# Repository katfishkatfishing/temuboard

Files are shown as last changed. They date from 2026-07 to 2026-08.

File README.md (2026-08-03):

# temuboard



A compact 75% mechanical keyboard taken inspiration from the Keycool 84, that has a rotary encoder, and a small OLED display.

---

## Features

- **79 keys**
- **EC11 Rotary Encoder** - rotation bound to volume
- **128x64 I2C Display** - to play tiny animations
- **QMK firmware** - for STM32F405 MCUs
- **Bottom mount style** - Bottom case, plate, Cherry MX switches, top case

---

## Case Bottom

Case screws: M3





---

## Case Top




---

## Plate


1.5mm thickness

## Pin Mapping

| Function | Pin |
| --- | ---|
| Columns (col 1-15) | PA 0-2,6,7, PB 12-15, PC 4-9 |
| Row (row 1-6) | PA3, PB 0-2, 10,11 |
| Encoder A/B | PA8/PA10 |
| OLED SDA/SCL | PB6/PB7 |







---
## Firmware
- Uses QMK firmware
- Has only 1 layer
- Replaced right FN key to open task manager
- Programmed OLED display to play animations with 2 frames
- QMK firmware defaults rotary encoder to control volume
---
## PCB/Assembly Note
- All components are to be hand soldered, including SMD components
---
## Lessons learnt
- As a complete beginner to these things, I learnt so much about, planning out schematics, routing PCBs, and CAD. When I first started this project I didn't even know I had to make the keyboard layout. So, I had a friend of mine (thephantompx) that has more experience to guide me through the first few days of using Kicad and setting up the schematics. He gave me advice on the components needed, how to connect them, and also taught me how to route the PCB. We ran out of I/O pins on the Pico pi so we found a suitable MCU and made our own board. CAD was horrid. I used FreeCAD because OnShape was laggy for me. It took me 2 days to figure out how to even make a sketch, and the tutorial I was following didn't really teach too much of what I needed, just enough to get me started. Tbh I didn't think it'd take this long, but then again I started with literally 0 experience. This project was a great opportunity for me to use my free time to get experience on how to design things.

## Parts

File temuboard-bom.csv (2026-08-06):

Item | Parts | Qty | Price(USD) | Link
Ceramic capacitor | 10nF 0603 | 1 | 0.81 | https://www.aliexpress.com/item/1005007137284660.html
Ceramic capacitor | 4.7uF 0805 | 2 | 1.61 | https://www.aliexpress.com/item/1005007533370902.html
Ceramic capacitor | 100nF 0201 | 7 | 2.97 | https://www.aliexpress.com/item/1005005961370114.html
Ceramic capacitor | 33pF 0201 | 2 | 0.60 | https://www.aliexpress.com/item/1005008331136790.html
Ceramic capacitor | 10uF 0805 | 1 | 1.92 | https://www.aliexpress.com/item/1005007533370902.html
Ceramic capacitor | 22uF 0805 | 1 | 2.22 | https://www.aliexpress.com/item/1005007533370902.html
Ceramic capacitor | 2.2uF 0603 | 2 | 2.26 | https://www.aliexpress.com/item/1005012364450156.html?curPageLogUid=KfSrYjbxI3hv
Diode | 1N4148 SOD27 | 79 | 1.63 | https://www.aliexpress.com/item/1005009379098965.html
Ferrite Bead | 120R@100MHz 0603 | 1 | 1.04 | https://www.aliexpress.com/item/1005009841998170.html
USB C RECEPTACLE | USB4085 | 1 | 6.26 | https://www.aliexpress.com/item/1005010442732661.html
Connector Pin Socket | PinSocket_1x04_P2.54mm_Vertical | 1 | 3.27 | https://www.aliexpress.com/item/1005004122312694.html
Resistor | R_0603_1608Metric_Pad0.98x0.95mm_HandSolder 5k1 | 2 | 0.3 | https://www.aliexpress.com/item/1005008628279880.html
Resistor | R_0603_1608Metric_Pad0.98x0.95mm_HandSolder 1m | 1 | 2.05 | https://www.aliexpress.com/item/1005011779883974.html
Resistor | R_0603_1608Metric_Pad0.98x0.95mm_HandSolder 10k | 2 | 0.3 | https://www.aliexpress.com/item/1005008628279880.html
MX Stablizer | 2u | 1 | 0.99 | https://www.aliexpress.com/item/1005006969058970.html
MX Stablizer | 2.25u | 2 | 0.99 | https://www.aliexpress.com/item/1005006969058970.html
MX Stabilizer | 6.25u | 1 | 0.99 | https://www.aliexpress.com/item/1005006969058970.html
Button | SW_SPST_B3U-1000P | 2 | 0.16 | https://www.aliexpress.com/item/1005008817464692.html
Rotary Encoder Switch | EC11 | 1 | 0.06 | https://www.alibaba.com/product-detail/EC11-rotary-15-20mm-Meihua-Bing_1600985459709.html
Cherry MX Switch | Cherry MX Brown | 79 | 11.83 | https://www.aliexpress.com/item/1005002378701948.html?gatewayAdapt=usa2glo4itemAdapt
ESD Protection Diode | USBLC6-2SC6 | 1 | 3.13 | https://www.aliexpress.com/item/1005007348100430.html
Linear Regulator | AMS1117-3.3 | 1 | 0.60 | https://www.aliexpress.com/item/1005009000664335.html
Microcontroller | STM32F405RGT6 | 1 | 3.15 | https://www.aliexpress.com/item/4000117720745.html
0.91 inch OLED Display | SSD1306 | 1 | 1.20 | https://www.aliexpress.com/item/32836691660.html?gatewayAdapt=usa2glo4itemAdapt
Crystal Oscillator | X322525MOB4SI | 1 | 1.50 | https://www.aliexpress.com/item/1005008501683836.html
Keycaps | Cherry MX hiragana Keycaps | 79 | 37.49 | https://www.aliexpress.com/item/1005006113224623.html
Rotary Encoder Knob | D-shaft 15mmx10mm | 1 | 1.49 | https://www.aliexpress.com/item/1005005751465974.html

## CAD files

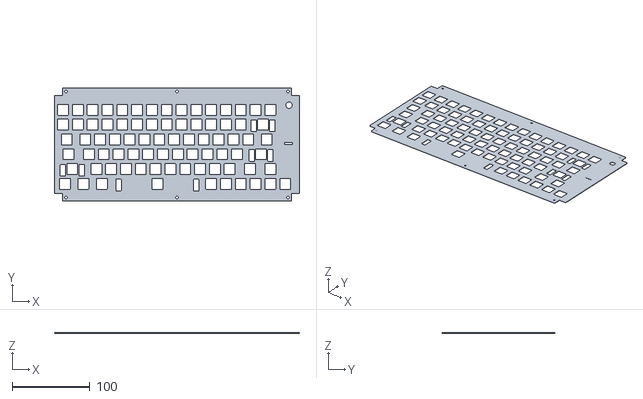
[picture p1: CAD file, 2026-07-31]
CAD/KeybodPlate.stl
315.0 x 145.7 x 1.50

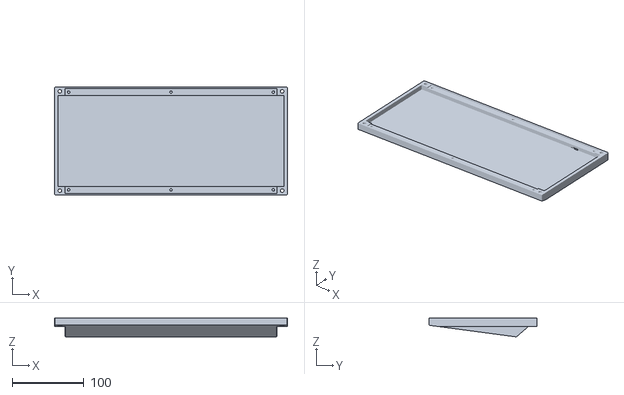
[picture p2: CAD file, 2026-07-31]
CAD/KeybodCaseBottom.stl
325.0 x 150.0 x 26.2

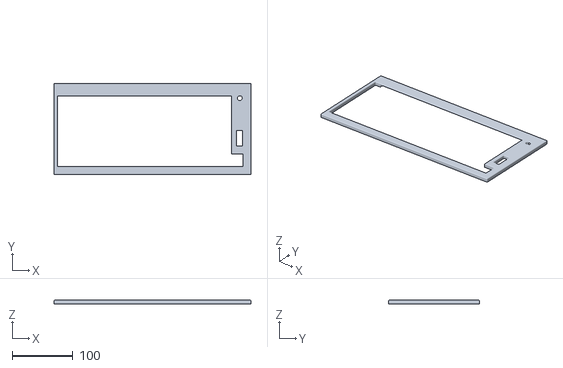
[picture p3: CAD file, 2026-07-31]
CAD/KeybodCaseTop.stl
325.0 x 150.0 x 6.00

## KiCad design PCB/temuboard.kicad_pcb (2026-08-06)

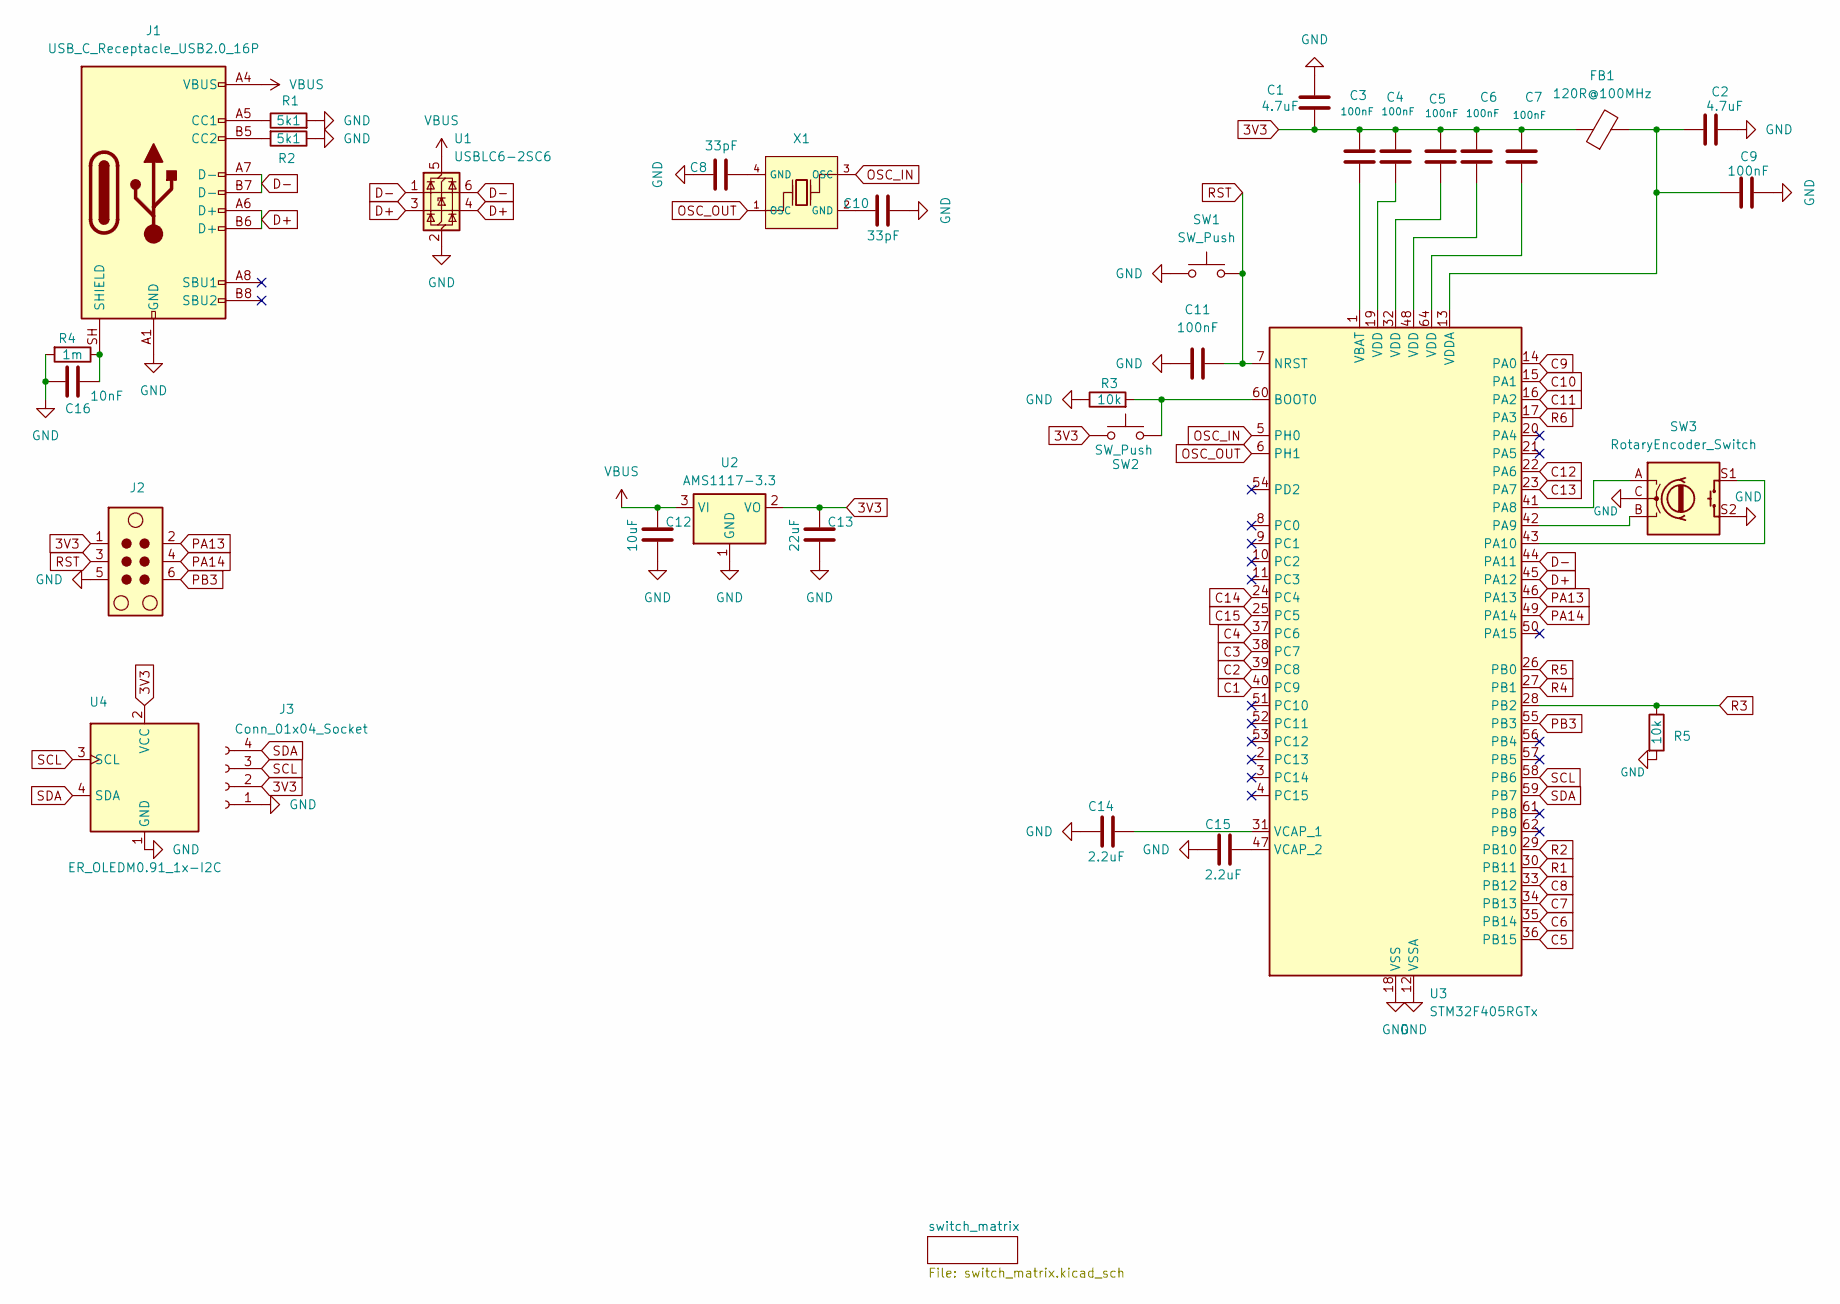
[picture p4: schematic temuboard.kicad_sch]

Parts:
C1, C2: 4.7uF; C_0805_2012Metric; LCSC Part # C98192
C3, C4, C5, C6, C7, C9, C11: 100nF; C_0201_0603Metric; LCSC Part # C76939
C8, C10: 33pF; C_0201_0603Metric; LCSC Part # C56903
C12: 10uF; C_0805_2012Metric; LCSC Part # C440198
C13: 22uF; C_0805_2012Metric; LCSC Part # C48986262
C14, C15: 2.2uF; C_0603_1608Metric; LCSC Part # C162273
C16: 10nF; C_0603_1608Metric; LCSC Part # C1589
FB1: 120R@100MHz; FB_0603; LCSC Part # C14709
J1: USB_C_Receptacle_USB2.0_16P; USB_C_Receptacle_GCT_USB4085; LCSC Part # C7095263
J2: TC2030; Tag-Connect_TC2030-IDC-NL_2x03_P1.27mm_Vertical
J3: Conn_01x04_Socket; PinSocket_1x04_P2.54mm_Vertical
R1, R2: 5k1; R_0603_1608Metric_Pad0.98x0.95mm_HandSolder
R3: 10k; R_0603_1608Metric_Pad0.98x0.95mm_HandSolder
R4: 1m; R_0603_1608Metric_Pad0.98x0.95mm_HandSolder
R5: 10k; C_0603_1608Metric_Pad1.08x0.95mm_HandSolder
SW1, SW2: SW_Push; SW_SPST_B3U-1000P; LCSC Part # C231329
SW3: RotaryEncoder_Switch; RotaryEncoder_Alps_EC11E-Switch_Vertical_H20mm
U1: USBLC6-2SC6; SOT-23-6; LCSC Part # C2687116
U2: AMS1117-3.3; SOT-223-3_TabPin2; LCSC Part # C351784
U3: STM32F405RGTx; LQFP-64_10x10mm_P0.5mm; LCSC Part # C15742
U4: ER_OLEDM0.91_1x-I2C
X1: X322525MOB4SI; OSC-SMD_4P-L3.2-W2.5-BL; Frequency Tolerance ±10ppm; Part X322525MOB4SI; LCSC C9006

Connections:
3V3: C1.2, C3.1, C4.2, C5.1, C6.2, C7.2, C13.1, FB1.1, J2.1, J3.2, SW2.1, U2.2 (VO), U4.2 (VCC)
C1: U3.40 (PC9); also elsewhere on the board
C2: U3.39 (PC8); also elsewhere on the board
C3: U3.38 (PC7); also elsewhere on the board
C4: U3.37 (PC6); also elsewhere on the board
C5: U3.36 (PB15); also elsewhere on the board
C6: U3.35 (PB14); also elsewhere on the board
C7: U3.34 (PB13); also elsewhere on the board
C8: U3.33 (PB12); also elsewhere on the board
C9: U3.14 (PA0); also elsewhere on the board
C10: U3.15 (PA1); also elsewhere on the board
C11: U3.16 (PA2); also elsewhere on the board
C12: U3.22 (PA6); also elsewhere on the board
C13: U3.23 (PA7); also elsewhere on the board
C14: U3.24 (PC4); also elsewhere on the board
C15: U3.25 (PC5); also elsewhere on the board
D+: J1.A6 (D+), J1.B6 (D+), U1.3 (I/O2), U1.4 (I/O2), U3.45 (PA12)
D-: J1.A7 (D-), J1.B7 (D-), U1.1 (I/O1), U1.6 (I/O1), U3.44 (PA11)
GND: C1.1, C2.1, C8.1, C9.1, C10.2, C11.1, C12.2, C13.2, C14.1, C15.1, C16.1, J1.A1 (GND), J1.A12 (GND), J1.B1 (GND), J1.B12 (GND), J2.5, J3.1, R1.2, R2.1, R3.1, R4.2, R5.2, SW1.1, SW3.C, SW3.S2, U1.2 (GND), U2.1 (GND), U3.12 (VSSA), U3.18 (VSS), U3.63 (VSS), U4.1 (GND)
unnamed: C4.1, U3.19 (VDD)
unnamed: C5.2, U3.32 (VDD)
unnamed: C6.1, U3.48 (VDD)
unnamed: C7.1, U3.64 (VDD)
unnamed: C8.2, X1.4 (GND)
unnamed: C10.1, X1.2 (GND)
unnamed: J1.A5 (CC1), R1.1
unnamed: J1.B5 (CC2), R2.2
unnamed: C16.2, J1.SH (SHIELD), R4.1
unnamed: R3.2, SW2.2, U3.60 (BOOT0)
unnamed: SW3.A, U3.41 (PA8)
unnamed: SW3.B, U3.42 (PA9)
unnamed: SW3.S1, U3.43 (PA10)
unnamed: C3.2, U3.1 (VBAT)
unnamed: C14.2, U3.31 (VCAP_1)
unnamed: C15.2, U3.47 (VCAP_2)
unnamed: C2.2, C9.2, FB1.2, U3.13 (VDDA)
OSC_IN: U3.5 (PH0), X1.3 (OSC)
OSC_OUT: U3.6 (PH1), X1.1 (OSC)
PA13: J2.2, U3.46 (PA13)
PA14: J2.4, U3.49 (PA14)
PB3: J2.6, U3.55 (PB3)
R1: U3.30 (PB11); also elsewhere on the board
R2: U3.29 (PB10); also elsewhere on the board
R3: R5.1, U3.28 (PB2); also elsewhere on the board
R4: U3.27 (PB1); also elsewhere on the board
R5: U3.26 (PB0); also elsewhere on the board
R6: U3.17 (PA3); also elsewhere on the board
RST: C11.2, J2.3, SW1.2, U3.7 (NRST)
SCL: J3.3, U3.58 (PB6), U4.3 (SCL)
SDA: J3.4, U3.59 (PB7), U4.4 (SDA)
VBUS: C12.1, J1.A4 (VBUS), J1.A9 (VBUS), J1.B4 (VBUS), J1.B9 (VBUS), U1.5 (VBUS), U2.3 (VI)

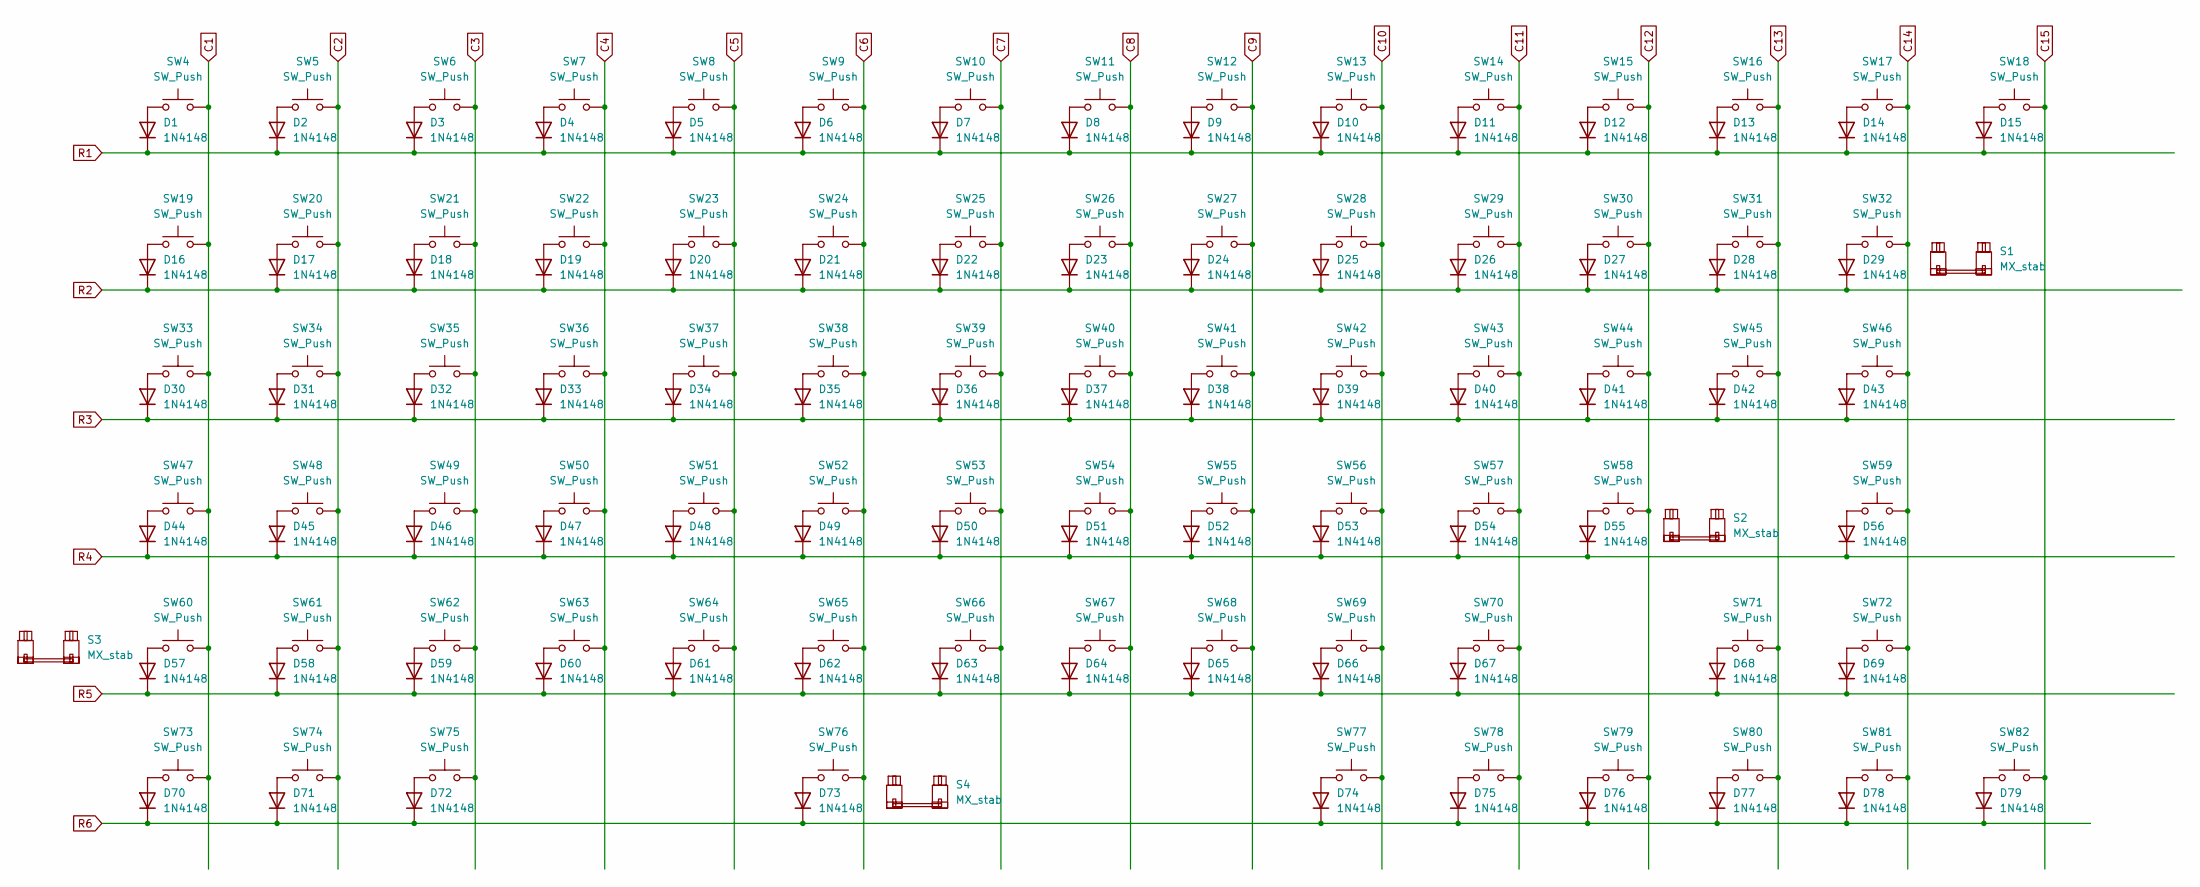
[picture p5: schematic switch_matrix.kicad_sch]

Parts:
D1, D2, D3, D4, D5, D6, D7, D8, D9, D10, D11, D12, D13, D14, D15, D16, D17, D18, D19, D20, D21, D22, D23, D24, D25, D26, D27, D28, D29, D30, D31, D32, D33, D34, D35, D36, D37, D38, D39, D40, D41, D42, D43, D44, D45, D46, D47, D48, D49, D50, D51, D52, D53, D54, D55, D56, D57, D58, D59, D60, D61, D62, D63, D64, D65, D66, D67, D68, D69, D70, D71, D72, D73, D74, D75, D76, D77, D78, D79: 1N4148; D_DO-35_SOD27_P7.62mm_Horizontal
S1: MX_stab; STAB_MX_P_2u
S2, S3: MX_stab; STAB_MX_P_2.25u
S4: MX_stab; STAB_MX_P_6.25u
SW4, SW5, SW6, SW7, SW8, SW9, SW10, SW11, SW12, SW13, SW14, SW15, SW16, SW17, SW18, SW19, SW20, SW21, SW22, SW23, SW24, SW25, SW26, SW27, SW28, SW29, SW30, SW31, SW32, SW33, SW34, SW35, SW36, SW37, SW38, SW39, SW40, SW41, SW42, SW43, SW44, SW45, SW46, SW47, SW48, SW49, SW50, SW51, SW52, SW53, SW54, SW55, SW56, SW57, SW58, SW59, SW60, SW61, SW62, SW63, SW64, SW65, SW66, SW67, SW68, SW69, SW70, SW71, SW72, SW73, SW74, SW75, SW76, SW77, SW78, SW79, SW80, SW81, SW82: SW_Push; SW_MX_HS_CPG151101S11_1u

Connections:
C1: SW4.2, SW19.2, SW33.2, SW47.2, SW60.2, SW73.2; also elsewhere on the board
C2: SW5.2, SW20.2, SW34.2, SW48.2, SW61.2, SW74.2; also elsewhere on the board
C3: SW6.2, SW21.2, SW35.2, SW49.2, SW62.2, SW75.2; also elsewhere on the board
C4: SW7.2, SW22.2, SW36.2, SW50.2, SW63.2; also elsewhere on the board
C5: SW8.2, SW23.2, SW37.2, SW51.2, SW64.2; also elsewhere on the board
C6: SW9.2, SW24.2, SW38.2, SW52.2, SW65.2, SW76.2; also elsewhere on the board
C7: SW10.2, SW25.2, SW39.2, SW53.2, SW66.2; also elsewhere on the board
C8: SW11.2, SW26.2, SW40.2, SW54.2, SW67.2; also elsewhere on the board
C9: SW12.2, SW27.2, SW41.2, SW55.2, SW68.2; also elsewhere on the board
C10: SW13.2, SW28.2, SW42.2, SW56.2, SW69.2, SW77.2; also elsewhere on the board
C11: SW14.2, SW29.2, SW43.2, SW57.2, SW70.2, SW78.2; also elsewhere on the board
C12: SW15.2, SW30.2, SW44.2, SW58.2, SW79.2; also elsewhere on the board
C13: SW16.2, SW31.2, SW45.2, SW71.2, SW80.2; also elsewhere on the board
C14: SW17.2, SW32.2, SW46.2, SW59.2, SW72.2, SW81.2; also elsewhere on the board
C15: SW18.2, SW82.2; also elsewhere on the board
unnamed: D1.2 (A), SW4.1
unnamed: D2.2 (A), SW5.1
unnamed: D3.2 (A), SW6.1
unnamed: D4.2 (A), SW7.1
unnamed: D5.2 (A), SW8.1
unnamed: D6.2 (A), SW9.1
unnamed: D7.2 (A), SW10.1
unnamed: D8.2 (A), SW11.1
unnamed: D9.2 (A), SW12.1
unnamed: D10.2 (A), SW13.1
unnamed: D11.2 (A), SW14.1
unnamed: D12.2 (A), SW15.1
unnamed: D13.2 (A), SW16.1
unnamed: D14.2 (A), SW17.1
unnamed: D15.2 (A), SW18.1
unnamed: D16.2 (A), SW19.1
unnamed: D17.2 (A), SW20.1
unnamed: D18.2 (A), SW21.1
unnamed: D19.2 (A), SW22.1
unnamed: D20.2 (A), SW23.1
unnamed: D21.2 (A), SW24.1
unnamed: D22.2 (A), SW25.1
unnamed: D23.2 (A), SW26.1
unnamed: D24.2 (A), SW27.1
unnamed: D25.2 (A), SW28.1
unnamed: D26.2 (A), SW29.1
unnamed: D27.2 (A), SW30.1
unnamed: D28.2 (A), SW31.1
unnamed: D29.2 (A), SW32.1
unnamed: D30.2 (A), SW33.1
unnamed: D31.2 (A), SW34.1
unnamed: D32.2 (A), SW35.1
unnamed: D33.2 (A), SW36.1
unnamed: D34.2 (A), SW37.1
unnamed: D35.2 (A), SW38.1
unnamed: D36.2 (A), SW39.1
unnamed: D37.2 (A), SW40.1
unnamed: D38.2 (A), SW41.1
unnamed: D39.2 (A), SW42.1
unnamed: D40.2 (A), SW43.1
unnamed: D41.2 (A), SW44.1
unnamed: D42.2 (A), SW45.1
unnamed: D43.2 (A), SW46.1
unnamed: D44.2 (A), SW47.1
unnamed: D45.2 (A), SW48.1
unnamed: D46.2 (A), SW49.1
unnamed: D47.2 (A), SW50.1
unnamed: D48.2 (A), SW51.1
unnamed: D49.2 (A), SW52.1
unnamed: D50.2 (A), SW53.1
unnamed: D51.2 (A), SW54.1
unnamed: D52.2 (A), SW55.1
unnamed: D53.2 (A), SW56.1
unnamed: D54.2 (A), SW57.1
unnamed: D55.2 (A), SW58.1
unnamed: D56.2 (A), SW59.1
unnamed: D57.2 (A), SW60.1
unnamed: D58.2 (A), SW61.1
unnamed: D59.2 (A), SW62.1
unnamed: D60.2 (A), SW63.1
unnamed: D61.2 (A), SW64.1
unnamed: D62.2 (A), SW65.1
unnamed: D63.2 (A), SW66.1
unnamed: D64.2 (A), SW67.1
unnamed: D65.2 (A), SW68.1
unnamed: D66.2 (A), SW69.1
unnamed: D67.2 (A), SW70.1
unnamed: D68.2 (A), SW71.1
unnamed: D69.2 (A), SW72.1
unnamed: D70.2 (A), SW73.1
unnamed: D71.2 (A), SW74.1
unnamed: D72.2 (A), SW75.1
unnamed: D73.2 (A), SW76.1
unnamed: D74.2 (A), SW77.1
unnamed: D75.2 (A), SW78.1
unnamed: D76.2 (A), SW79.1
unnamed: D77.2 (A), SW80.1
unnamed: D78.2 (A), SW81.1
unnamed: D79.2 (A), SW82.1
R1: D1.1 (K), D2.1 (K), D3.1 (K), D4.1 (K), D5.1 (K), D6.1 (K), D7.1 (K), D8.1 (K), D9.1 (K), D10.1 (K), D11.1 (K), D12.1 (K), D13.1 (K), D14.1 (K), D15.1 (K); also elsewhere on the board
R2: D16.1 (K), D17.1 (K), D18.1 (K), D19.1 (K), D20.1 (K), D21.1 (K), D22.1 (K), D23.1 (K), D24.1 (K), D25.1 (K), D26.1 (K), D27.1 (K), D28.1 (K), D29.1 (K); also elsewhere on the board
R3: D30.1 (K), D31.1 (K), D32.1 (K), D33.1 (K), D34.1 (K), D35.1 (K), D36.1 (K), D37.1 (K), D38.1 (K), D39.1 (K), D40.1 (K), D41.1 (K), D42.1 (K), D43.1 (K); also elsewhere on the board
R4: D44.1 (K), D45.1 (K), D46.1 (K), D47.1 (K), D48.1 (K), D49.1 (K), D50.1 (K), D51.1 (K), D52.1 (K), D53.1 (K), D54.1 (K), D55.1 (K), D56.1 (K); also elsewhere on the board
R5: D57.1 (K), D58.1 (K), D59.1 (K), D60.1 (K), D61.1 (K), D62.1 (K), D63.1 (K), D64.1 (K), D65.1 (K), D66.1 (K), D67.1 (K), D68.1 (K), D69.1 (K); also elsewhere on the board
R6: D70.1 (K), D71.1 (K), D72.1 (K), D73.1 (K), D74.1 (K), D75.1 (K), D76.1 (K), D77.1 (K), D78.1 (K), D79.1 (K); also elsewhere on the board

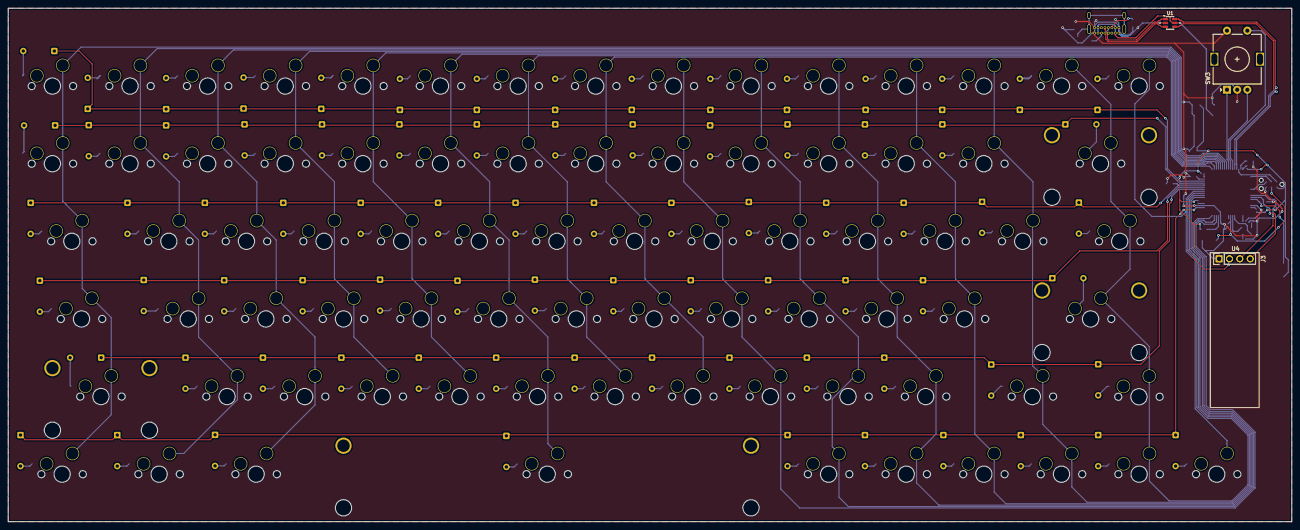
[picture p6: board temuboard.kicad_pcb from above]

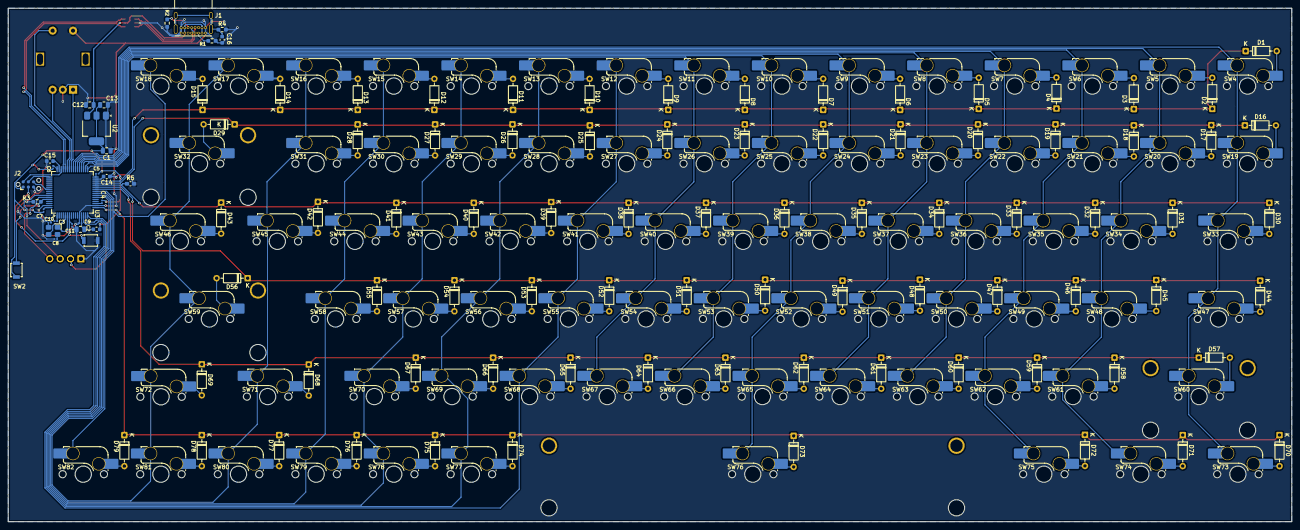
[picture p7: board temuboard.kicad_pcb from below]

Board: 2 copper layers, 315.0 x 126.0 mm, 195 parts (187 on the bottom side), 130 nets.

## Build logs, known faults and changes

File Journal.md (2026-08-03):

## Build Journal
  Hours: 72 
  - Everything was recorded in Lapse: https://lapse.hackclub.com/user/@jian
  ---

## Entry 1 - Figuring out the layout
**Date: July 16th**
- I went to https://www.keyboard-layout-editor.com to figure out what layout i wanted, im currently using a 60%, and i really needed function keys and the arrow keys
so i picked the Keycool84, and slightly modified it.

$$\color{red}{**Total \space hours: \space 1**}$$

keyboard-layout
https://lapse.hackclub.com/timelapse/-kUr7TK3-eP2

- 1hr timelapse that only recorded the kicad homepage cuz i was stupid and only selected that window

## Entry 2 - Planning out the schematics
**Date: July 18th**
- I followed the guide for this, until i found out i did not have enough i/o pins, so i switched to the STM32F405RGT6 mcu and added all other necessary components, 
with help from my friend. 

$$\color{red}{**Total \space hours: \space 1**}$$


https://lapse.hackclub.com/timelapse/EOpBaJheHwFZ

## Entry 3 - Assigning footprints and then layout in PCB + redo switch matrix
**Date: July 19th**
- downloading libs and footprints then assigning them, then doing the layout for the PCB, then reach enlightenment and redo switch matrix

$$\color{red}{**Total \space hours: \space 4**}$$


https://lapse.hackclub.com/timelapse/TPhGV8h5PCIk

## Entry 4 - More designing the layout of PCB, then some prep for routing traces
**Date: July 20th**
- same as header, moved around components and tried to gather as much space as possible for the mcu and traces

$$\color{red}{**Total \space hours: \space 4**}$$


https://lapse.hackclub.com/timelapse/01aFHcZoXgP2

## Entry 5 - Start to route traces
**Date: July 20th**
- moved mcu to better spot then route traces, felt like i was in hell tbh, sososo tedious

$$\color{red}{**Total \space hours: \space 6**}$$


https://lapse.hackclub.com/timelapse/SX4pOZ0vFfX8

## Entry 6 - Still routing pcb then started CAD
**Date: July 21st**
- routing traces ahhhhhhh, then spent 2 hours figuring out how to even use freeeeecad

$$\color{red}{**Total \space hours: \space 5(3+2)**}$$


https://lapse.hackclub.com/timelapse/W9iDYJItnsjG

## Entry 7 - Resolving errors in pcb then figuring out the case design in freecad
**Date: July 22nd**
- Uh i was just going with the flow tbh, im not familiar with freecad and have no idea how to make the shape i want

$$\color{red}{**Total \space hours: \space 3**}$$


https://lapse.hackclub.com/timelapse/Svkw7hLlLJWZ

## Entry 8 - Assigning 3d models
**Date: July 23rd**
- Spent the entire day adding switch and keycap 3d model to the switches, this took me so long 

$$\color{red}{**Total \space hours: \space 4**}$$


https://lapse.hackclub.com/timelapse/a-GTi7Kvh6lG

## Entry 9 - Shaving off pcb size+ resolving errors in PCB again + working on CAD
**Date: July 23rd**
- Fixed various errors and had to ask my friend how to fix the thermal relief connection error thing, then continued working on the case

$$\color{red}{**Total \space hours: \space 3.5**}$$


https://lapse.hackclub.com/timelapse/H3K_OknX04cl

## Entry 10 - Re-redesigning PCB
**Date: July 24th**
- My rotary encoder was wayy too close to the keys so i had to move some components to make space, and then moved the usbc receptacle to a better spot
then worked a bit on the case

$$\color{red}{**Total \space hours: \space 2**}$$


https://lapse.hackclub.com/timelapse/BAj46pmvDyro

## Entry 11 - Worked in freecad
**Date: July 25th**
- Was just staring a freecad, i had the shape i want in my head, but i had no idea how to translate that into freecad so i just stared at the screen
then i also picked the bottom mount at this point since i dont need the gasket mount silence.

$$\color{red}{**Total \space hours: \space 1**}$$


https://lapse.hackclub.com/timelapse/ambSWWBhd6hI

## Entry 12 - Struggle is real in freecad
**Date: July 26th**
- Slowly picking up how to use freecad (kinda?) reworked the case bottom, then picked up my notebook and started sketching to help translate it into freecad

$$\color{red}{**Total \space hours: \space 2**}$$


https://lapse.hackclub.com/timelapse/bbK7ev6hEqQV

## Entry 13 - More CAD
**Date: July 27th**
- More cad, kinda know how to use freecad now, added holes to the plate for the display and the rotary encoder. reaching abt 70% done for the case

$$\color{red}{**Total \space hours: \space 3**}$$




- me adding exported geometry and it not being on the subshape binder, confused me
https://lapse.hackclub.com/timelapse/y4ROOh121kIA

## Entry 14 - Exploring the limits of freecad and my laptop
**Date: July 27th**
- decided i should make a sketch of the plate instead of just using the imported part so that i could make a custom plate, when sketching everytime i do anything,
freecad freezes for like a minute, i had like 700 elements in that sketch, so it lagged like hell, i didnt have any other solutions for this so i kept going for
3 hours

$$\color{red}{**Total \space hours: \space 4**}$$


- freecad not responding 
https://lapse.hackclub.com/timelapse/5D4HYUurXi5z

## Entry 15 - Freecad.exe is not responding pt.2
**Date: July 28th**
- im still working on the plate, the sketch isnt finished, so i kept going until it couldnt hold it anymore, and then found out i could combine sketches, so i made
a second one, but when i combined them it doesnt include the imported geometry, devestated 

$$\color{red}{**Total \space hours: \space 5.5**}$$




https://lapse.hackclub.com/timelapse/GhMEoF24iOgX

## Entry 16 - cadhell 4
**Date: July 29th**
- i learnt how to turn draft into sketch but its not what i need, then i somehow was able to import the geometry of the other sketch onto a new sketch, when i
deleted an element, the entire thing goes, i have no idea why and no idea how to replicate it, i worked around it since it was what i needed, finished up the
plate, then aligned the plate, pcb and the case bottom, and finding out the usbc receptacle is in between everything

$$\color{red}{**Total \space hours: \space 2.5**}$$



https://lapse.hackclub.com/timelapse/DjHF61wVqImW

## Entry 17 - Cad and back to PCB
**Date: July 29th**
- added indents to bottom case to screw in the plate, then added screw mounts to bottom case. then i rerouted the usbc receptacle cuz i had to flip it to the back,
it was either hell to cad since the receptacle was in between everything, or hell in pcb cuz the d+/d- lines are crossed when the receptacle is flipped to the back

$$\color{red}{**Total \space hours: \space 4**}$$



- asking my friend if this was ok lol


https://lapse.hackclub.com/timelapse/XdTzAYLo_5n_

## Entry 18 - Reworking the plate
**Date: July 30th**
- reworking pt1 of the plate sketch to make it bigger, but it turns out all that time was useless cuz it didnt even translate to the main sketch. didnt record 
much cuz it was just freecad freezing

$$\color{red}{**Total \space hours: \space 0.5**}$$


https://lapse.hackclub.com/timelapse/Epne4LsP45pM

## Entry 19 - Cad Endgame (for now hopefully)
**Date: July 30th**
- found out i could offset the sketches, reach enlightenment and be able to make shapes i wanted to make but couldnt before, added screw mounts to plate and case 
top, then made the case bottom look better, and added fillets

$$\color{red}{**Total \space hours: \space 2.5**}$$



https://lapse.hackclub.com/timelapse/PXnifbRMiL9P

## Entry 20 - Which is right now!
**Date: July 31st**
- originally wanted to start doing the firmware but i have no idea how to do that so i decided to start working on the repo. hello, me in the present.
uploaded files to the repo, updated the readme, and started writing this. i forgot to journal along the way so im only doing it now.

$$\color{red}{**Total \space hours: \space 3**}$$



https://lapse.hackclub.com/timelapse/J6mgZaVTLoea

## Entry 21 - Creating the BOM
**Date: July 31st**
- still putting off the firmware stuff cuz i dont understand it at all, created the bom and added two missing components to my sch and pcb

$$\color{red}{**Total \space hours: \space 2**}$$


https://lapse.hackclub.com/timelapse/EPAxlvIx_O3H

## Entry 22 - Learning QMK
**Date: August 1st**
- Had a fever so didnt do much work, found out rmk doesnt support the MCU im using, found QMK, read the docs, ultra confused and gave up for the day

  $$\color{red}{**Total \space hours: \space 1**}$$


https://lapse.hackclub.com/timelapse/cvJtFR6oS3Uj

## Entry 23 - Learning QMK pt2
**Date: August 2nd**
- Mostly well now, so now i can actually understand the docs, kinda figured out QMK, had some issues in the end

$$\color{red}{**Total \space hours: \space 4**}$$


https://lapse.hackclub.com/timelapse/vJUAeGbDEvav

## Entry 24 - Finalizing
**Date: August 3rd**
- Finishing things up, trying to use jlcpcb and making sure everything is ready before submitting

$$\color{red}{**Total \space hours: \space 2**}$$

https://lapse.hackclub.com/timelapse/2UFzCB3AZBFO

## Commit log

2026-07-31 Enhance README with project details and insights
    Expanded the README with detailed features, hardware specifications, case design, pin mapping, and lessons learned during the project.
2026-07-31 Revise BOM with new parts and pricing information
    [temuboard-bom.csv]
2026-07-31 Update temuboard-bom.csv with new components
    Added new components with details including price and links.
    [temuboard-bom.csv]
2026-07-31 Remove Tag Connector from temuboard-bom.csv
    Removed Tag Connector from the BOM.
    [temuboard-bom.csv]
2026-08-01 Update microcontroller model in BOM
    [temuboard-bom.csv]
2026-08-06 Update resistor quantity and add new items
    [temuboard-bom.csv]
